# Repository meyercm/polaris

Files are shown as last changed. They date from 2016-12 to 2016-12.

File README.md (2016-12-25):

# Upload Command

`platformio run --target upload` Build project and upload firmware to the all devices specified in Project Configuration File platformio.ini

## Current issues:

- Missing trace on board in upper right corner between I2C pull-up resistors
- Feather pin 9 is not capable of PWM, despite documentation.  can't use motor controllers
  as intended.

## Links

- [Ardunio example I2C](https://www.arduino.cc/en/Tutorial/DigitalPotentiometer)
- [Compass Datasheet](http://cache.freescale.com/files/sensors/doc/data_sheet/MAG3110.pdf)
- [Compass Appnote](http://www.nxp.com/assets/documents/data/en/application-notes/AN4984.pdf)

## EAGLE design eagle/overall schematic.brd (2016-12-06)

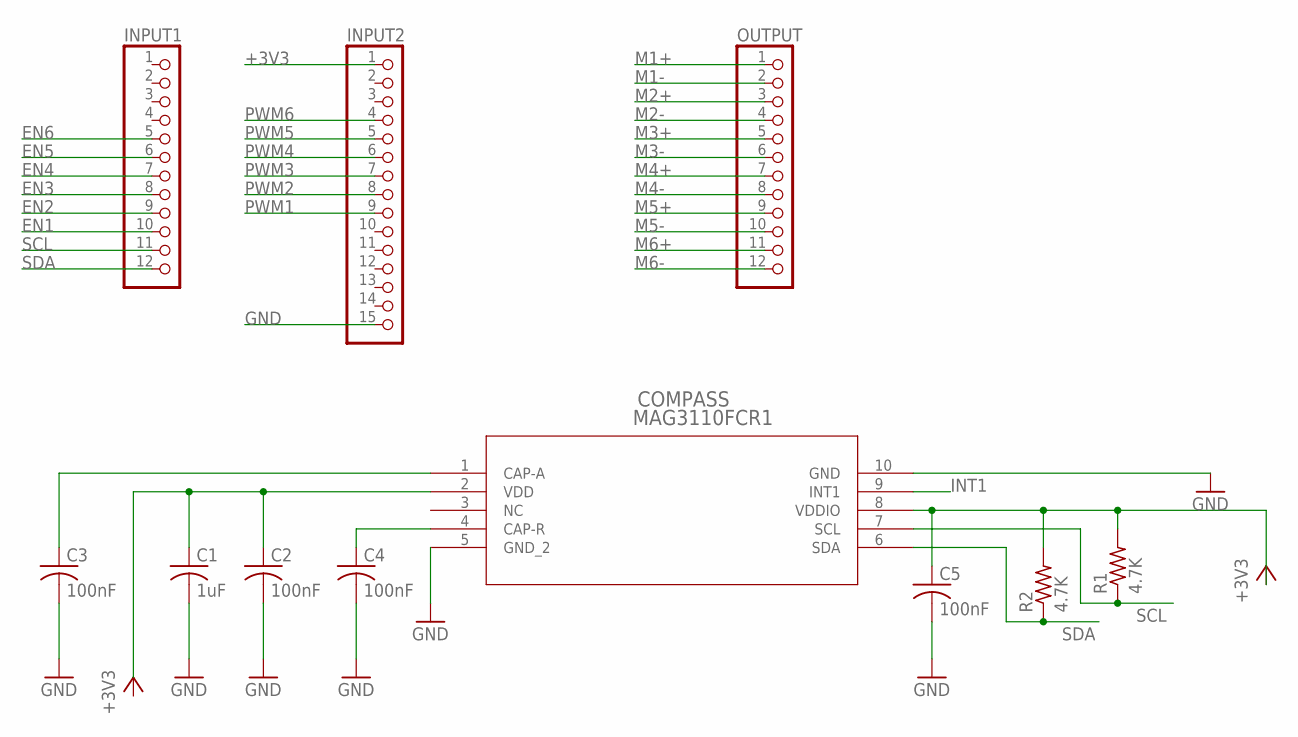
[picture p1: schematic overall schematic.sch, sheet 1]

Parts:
C1: 1uF; C0603
C2, C3, C4, C5: 100nF; C0603
COMPASS: MAG3110FCR1; DFN10
INPUT1: PINHD-1X12-CB; 1X12-CB
INPUT2: PINHD-1X15-CB; 1X15-CB
OUTPUT: PINHD-1X12-CB; 1X12-CB
R1, R2: 4.7K; R0603

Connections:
+3V3: C5.1, COMPASS.8 (VDDIO), INPUT2.1, R1.2, R2.2; also elsewhere on the board
CAP-A: C3.1, COMPASS.1 (CAP-A)
CAP-R: C4.1, COMPASS.4 (CAP-R)
EN1: INPUT1.10; also elsewhere on the board
EN2: INPUT1.9; also elsewhere on the board
EN3: INPUT1.8; also elsewhere on the board
EN4: INPUT1.7; also elsewhere on the board
EN5: INPUT1.6; also elsewhere on the board
EN6: INPUT1.5; also elsewhere on the board
GND: C1.2, C2.2, C3.2, C4.2, C5.2, COMPASS.5 (GND_2), COMPASS.10 (GND), INPUT2.15; also elsewhere on the board
INT1: COMPASS.9 (INT1)
M1+: OUTPUT.1; also elsewhere on the board
M1-: OUTPUT.2; also elsewhere on the board
M2+: OUTPUT.3; also elsewhere on the board
M2-: OUTPUT.4; also elsewhere on the board
M3+: OUTPUT.5; also elsewhere on the board
M3-: OUTPUT.6; also elsewhere on the board
M4+: OUTPUT.7; also elsewhere on the board
M4-: OUTPUT.8; also elsewhere on the board
M5+: OUTPUT.9; also elsewhere on the board
M5-: OUTPUT.10; also elsewhere on the board
M6+: OUTPUT.11; also elsewhere on the board
M6-: OUTPUT.12; also elsewhere on the board
unnamed: C1.1, C2.1, COMPASS.2 (VDD)
PWM1: INPUT2.9; also elsewhere on the board
PWM2: INPUT2.8; also elsewhere on the board
PWM3: INPUT2.7; also elsewhere on the board
PWM4: INPUT2.6; also elsewhere on the board
PWM5: INPUT2.5; also elsewhere on the board
PWM6: INPUT2.4; also elsewhere on the board
SCL: COMPASS.7 (SCL), INPUT1.11, R1.1
SDA: COMPASS.6 (SDA), INPUT1.12, R2.1

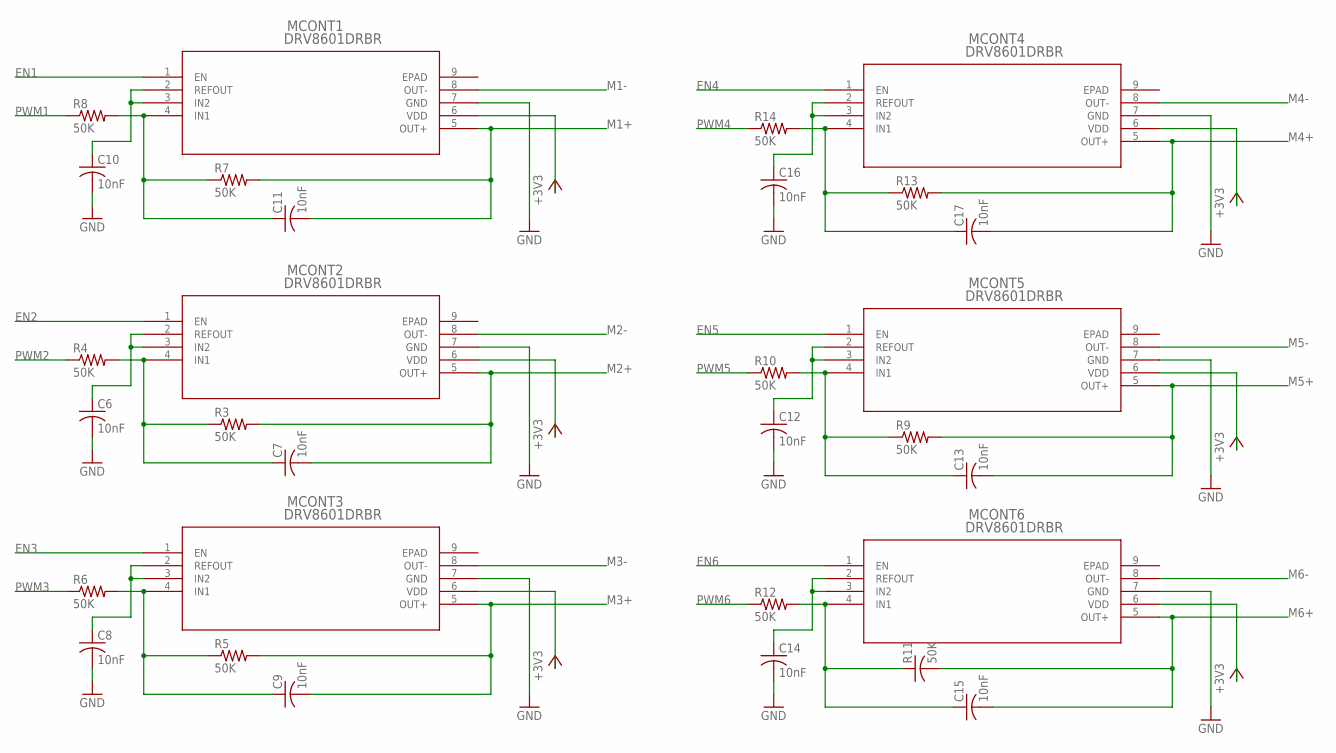
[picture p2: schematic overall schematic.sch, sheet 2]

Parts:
C6, C7, C8, C9, C10, C11, C12, C13, C14, C15, C16, C17: 10nF; C0603
MCONT1, MCONT2, MCONT3, MCONT4, MCONT5, MCONT6: DRV8601DRBR; DRB8_1P75X1P5
R3, R4, R5, R6, R7, R8, R9, R10, R12, R13, R14: 50K; R0603
R11: 50K; C0603

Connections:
+3V3: MCONT1.6 (VDD), MCONT2.6 (VDD), MCONT3.6 (VDD), MCONT4.6 (VDD), MCONT5.6 (VDD), MCONT6.6 (VDD); also elsewhere on the board
EN1: MCONT1.1 (EN); also elsewhere on the board
EN2: MCONT2.1 (EN); also elsewhere on the board
EN3: MCONT3.1 (EN); also elsewhere on the board
EN4: MCONT4.1 (EN); also elsewhere on the board
EN5: MCONT5.1 (EN); also elsewhere on the board
EN6: MCONT6.1 (EN); also elsewhere on the board
FB1: C11.1, MCONT1.4 (IN1), R7.1, R8.2
FB2: C7.1, MCONT2.4 (IN1), R3.1, R4.2
FB3: C9.1, MCONT3.4 (IN1), R5.1, R6.2
FB4: C17.1, MCONT4.4 (IN1), R13.1, R14.2
FB5: C13.1, MCONT5.4 (IN1), R9.1, R10.2
FB6: C15.1, MCONT6.4 (IN1), R11.1, R12.2
FBA1: C10.1, MCONT1.2 (REFOUT), MCONT1.3 (IN2)
FBA2: C6.1, MCONT2.2 (REFOUT), MCONT2.3 (IN2)
FBA3: C8.1, MCONT3.2 (REFOUT), MCONT3.3 (IN2)
FBA4: C16.1, MCONT4.2 (REFOUT), MCONT4.3 (IN2)
FBA5: C12.1, MCONT5.2 (REFOUT), MCONT5.3 (IN2)
FBA6: C14.1, MCONT6.2 (REFOUT), MCONT6.3 (IN2)
GND: C6.2, C8.2, C10.2, C12.2, C14.2, C16.2, MCONT1.7 (GND), MCONT2.7 (GND), MCONT3.7 (GND), MCONT4.7 (GND), MCONT5.7 (GND), MCONT6.7 (GND); also elsewhere on the board
M1+: C11.2, MCONT1.5 (OUT+), R7.2; also elsewhere on the board
M1-: MCONT1.8 (OUT-); also elsewhere on the board
M2+: C7.2, MCONT2.5 (OUT+), R3.2; also elsewhere on the board
M2-: MCONT2.8 (OUT-); also elsewhere on the board
M3+: C9.2, MCONT3.5 (OUT+), R5.2; also elsewhere on the board
M3-: MCONT3.8 (OUT-); also elsewhere on the board
M4+: C17.2, MCONT4.5 (OUT+), R13.2; also elsewhere on the board
M4-: MCONT4.8 (OUT-); also elsewhere on the board
M5+: C13.2, MCONT5.5 (OUT+), R9.2; also elsewhere on the board
M5-: MCONT5.8 (OUT-); also elsewhere on the board
M6+: C15.2, MCONT6.5 (OUT+), R11.2; also elsewhere on the board
M6-: MCONT6.8 (OUT-); also elsewhere on the board
PWM1: R8.1; also elsewhere on the board
PWM2: R4.1; also elsewhere on the board
PWM3: R6.1; also elsewhere on the board
PWM4: R14.1; also elsewhere on the board
PWM5: R10.1; also elsewhere on the board
PWM6: R12.1; also elsewhere on the board

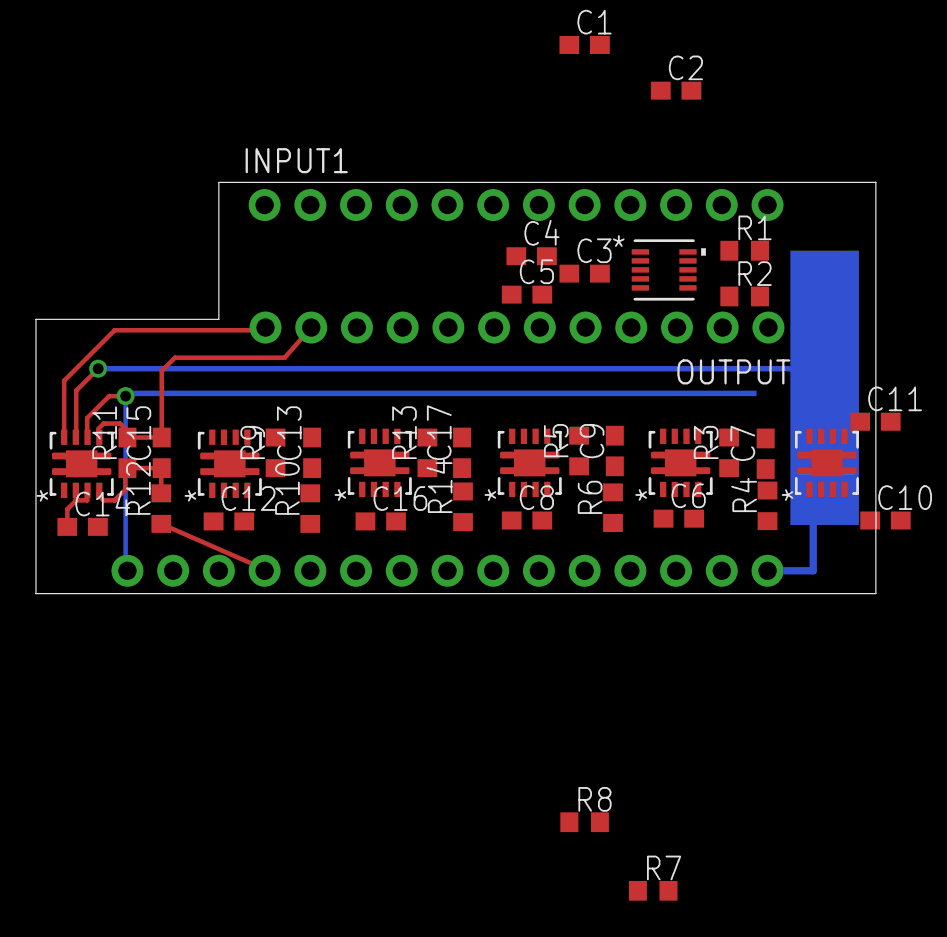
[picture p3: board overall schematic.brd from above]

Board: 2 copper layers, 46.7 x 22.9 mm, 41 parts (0 on the bottom side), 43 nets.

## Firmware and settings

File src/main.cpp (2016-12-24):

#include "Arduino.h"
#include <Wire.h>

#include "main.hpp"
#include "pins.hpp"
#include "compass.hpp"
#include "motors.hpp"

namespace {
  Compass compass;
  Motors motors;
  unsigned long last_measure;
  const long MEASURE_TIME = 1000L;
  bool new_measurement = false;
}

// the setup function runs once when you press reset or power the board
void setup() {
  setup_pins();
  attachInterrupt(INT_1, interrupt_handler, RISING);

  compass.initialize();
  motors.initialize();
  last_measure = millis();
}

void loop() {
  unsigned long now = millis();
  //Serial.write("loop\r\n");
  if (now > last_measure + MEASURE_TIME) {
    compass.request_measurement();
    last_measure = now;
  }
  if (new_measurement) {
    new_measurement = false;
    compass.read();
    motors.set_tones(compass.get_x(), compass.get_y(), compass.get_z(), now);
  }
  motors.update_motors(now);
  handle_serial();
}

void handle_serial(){
  switch (Serial.read()) {
    case -1:
      break;
    case 'c':
      Serial.print(" X: ");
      Serial.print(compass.get_x());
      Serial.print(" Y: ");
      Serial.print(compass.get_y());
      Serial.print(" Z: ");
      Serial.print(compass.get_z());
      Serial.print("\r\n");
      break;
    case 't':
      Serial.print(" millis: ");
      Serial.print(millis());
      Serial.print("\r\n");
      break;
    case 'd':
      Serial.print(" raw X: ");
      Serial.print(compass.x);
      Serial.print(" Y: ");
      Serial.print(compass.y);
      Serial.print(" Z: ");
      Serial.print(compass.z);
      Serial.print("\r\n");
      Serial.print("limits x:(");
      Serial.print(compass.min_x);
      Serial.print(",");
      Serial.print(compass.max_x);
      Serial.print(") y:(");
      Serial.print(compass.min_y);
      Serial.print(",");
      Serial.print(compass.max_y);
      Serial.print(") z:(");
      Serial.print(compass.min_z);
      Serial.print(",");
      Serial.print(compass.max_z);
      Serial.print(")\r\n");
      break;
  }
}

void interrupt_handler(void) {
  new_measurement = true;
}


void setup_pins(){
  pinMode(EN_1, OUTPUT);
  pinMode(EN_2, OUTPUT);
  pinMode(EN_3, OUTPUT);
  pinMode(EN_4, OUTPUT);
  pinMode(EN_5, OUTPUT);
  pinMode(EN_6, OUTPUT);
  pinMode(PWM_1, OUTPUT);
  pinMode(PWM_2, OUTPUT);
  pinMode(PWM_3, OUTPUT);
  pinMode(PWM_4, OUTPUT);
  pinMode(PWM_5, OUTPUT);
  pinMode(PWM_6, OUTPUT);
  pinMode(INT_1, OUTPUT);
}

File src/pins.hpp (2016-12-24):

#ifndef PINS_H
#define PINS_H

#include "arduino.h"

const int PWM_1 = 5;
const int PWM_2 = 6;
const int PWM_3 = 9;
const int PWM_4 = 10;
const int PWM_5 = 11;
const int PWM_6 = 12;
const int EN_1 = A5;
const int EN_2 = A4;
const int EN_3 = A3;
const int EN_4 = A2;
const int EN_5 = A1;
const int EN_6 = A0;
const int INT_1 = 13;

#endif

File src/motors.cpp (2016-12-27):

#include "motors.hpp"
namespace{
  const int MIN_POWER = 32;
  const int PERIOD = 20;

  class Motor {
  public:
    Motor(byte p_enable_pin, byte p_pwm_pin, float x, float y, float z){
      enable_pin = p_enable_pin;
      pwm_pin = p_pwm_pin;
      x_coord = x;
      y_coord = y;
      z_coord = z;
    }

    void update(unsigned long now){
      if (now >= turn_off_time){ turn_off(); }
      if (is_off){ return; }
      int cell = (now - start_time) % PERIOD;
      if (cell >= power_level) {
        digitalWrite(enable_pin, LOW);
      } else {
        digitalWrite(enable_pin, HIGH);
      }
    }

    void set_tone(int x, int y, int z, int duration, unsigned long now){
      // dot product, result is cos(theta) * magnitude:  0.0-255.0
      float power = (x * x_coord) + (y * y_coord) + (z * z_coord);
      if (power > MIN_POWER){
        turn_off_time = now + duration;
        //normalize to PERIOD
        power_level = (int)((power / (255.0)) * PERIOD);
        start_time = now;
        is_off = false;
      } else {
        turn_off();
      }
    }

    void turn_off(){
      digitalWrite(enable_pin, LOW);
      analogWrite(pwm_pin, 0);
      is_off = true;
    }
  private:
    byte enable_pin;
    byte pwm_pin;
    unsigned long turn_off_time;
    unsigned long start_time;
    int power_level;
    bool is_off = false;
    float x_coord;
    float y_coord;
    float z_coord;
  };

  Motor *motors[] = {
    new Motor(EN_1, PWM_1, -0.34, 0.8, 0.5), //120
    new Motor(EN_2, PWM_2, -0.34, -0.8, 0.5), //240
    // new Motor(EN_3, PWM_3), //180
    new Motor(EN_4, PWM_4, -0.34, 0.0, -0.94), //0
    // new Motor(EN_5, PWM_5), // 300
    // new Motor(EN_6, PWM_6), //60
  };
  int num_motors = 3;

  const int PULSE_DURATION = 100;
}

void Motors::initialize() {
  for(int i=0; i < num_motors; i++){
    motors[i]->turn_off();
  }
}

void Motors::set_tones(int x, int y, int z, unsigned long now){
  for(int i=0; i < num_motors; i++){
    motors[i]->set_tone(x, y, z, PULSE_DURATION, now);
  }
}

void Motors::update_motors(unsigned long now){
  for(int i=0; i < num_motors; i++){
    motors[i]->update(now);
  }
}

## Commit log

2016-12-06 add eagle design files
    [overall schematic.brd, overall schematic.gschem.sch, overall schematic.sch]
2016-12-24 motor controller 1 test
2016-12-24 not working, not sure why
    [compass.cpp, main.cpp, motors.cpp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]
2016-12-24 needed to be re-plugged. fixed normalization math
    [compass.cpp]
2016-12-25 functional, yet hacky motor control
2016-12-26 single motor, transform on
2016-12-27 only a single ring of motors, seems to work decently

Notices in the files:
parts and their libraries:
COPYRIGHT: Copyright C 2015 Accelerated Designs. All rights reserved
